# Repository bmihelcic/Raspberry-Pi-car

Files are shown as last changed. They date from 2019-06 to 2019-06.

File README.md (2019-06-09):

# Raspberry-Pi-car
Rpi car using L298n H-bridge.
You can either drive the car with your keyboard over ssh or you can download an app and drive the car over Bluetooth.

In this case battery pack was made from 3 Li-ion cells (18650 batteries) connected in series, outputing around 12V together. 12V were directly attached to Vin pin of the L298 module (with a switch in between), and also buck-converter was used to provide stable 5V (5.08 to be precise) to the Raspberry. It's worth to mention that buck converter's output should be calibrated to around 5.05 - 5.1 V otherwise Rpi reboots constantly because of inproper voltage. Also, Raspberry was running Raspbian OS.

There are also two 3D printed parts in the front for HC-sr04 sensors so it can be programmed for autonomous driving. Be sure to print one part as it is, and one which is mirrored. That could easily be done in slicer software like "Cura".
This mod is not fully developed, and obviously more sensors are needed.

Pin connections between Raspberry and L298 module

| Name | wiringPi | BCM	  | Physical |
| ---  |:---:| -----:| ---:|
| in1  | 0 | 17 	  | 11 |
| in2  | 1  	  | 18 	  | 12 | 
| in3  | 2  	  | 27 	  | 13 | 
| in4  | 3  	  | 22 | 15 |
| enA  | 26 	  | 12 | 32 | 
| enB  | 23 	  | 13 | 33 | 

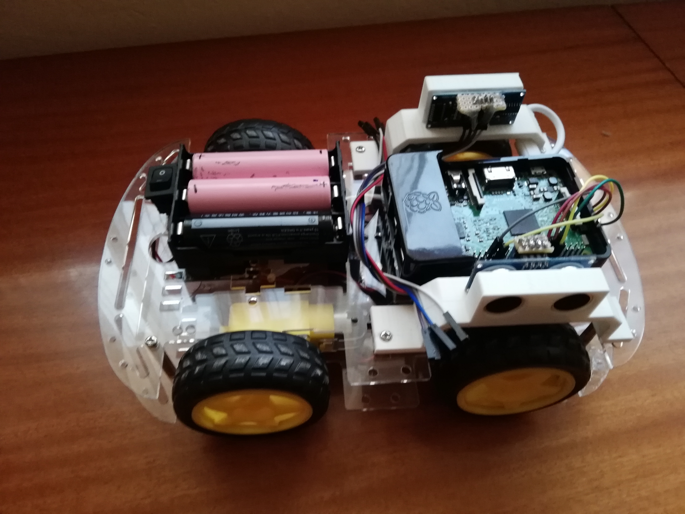
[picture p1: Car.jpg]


Parts list:<br>
<ul>
<li>1 set 4WD smart robot car chassis kit
<li>1 L298n DC motor driver module
<li>1 DC-DC buck converter
<li>1 battery holder for 3x 18650 Li-ion cells
<li>1 switch
<li>1 female USB type A connector (<i>optional</i>)
<li>1 micro USB cable
<li>x hot glue
<li>x doupont cables
<li>x soldering iron
<li>x wire cutter
</ul>

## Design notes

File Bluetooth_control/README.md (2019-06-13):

# Raspberry-Pi-car
Rpi car using L298n H-bridge and controlling with "Bluetooth RC Controller app".

Steps:
1. Firstly download "Arduino Bluetooth RC Car" app by Andi.Co on your smartphone.
2. Open file "sudo nano /etc/systemd/system/dbus-org.bluez.service" on Raspberry and edit two lines, it should look like:<br>
 	ExecStart=/usr/lib/bluetooth/bluetoothd -C<br>
	ExecStartPost=/usr/bin/sdptool add SP
3. Turn on Bluetooth on Raspberry and pair it with your phone (You need to pair mac addresses using "sudo bluetoothctl" command).
4. type "sudo rfcomm watch hci0" in terminal
5. In app on your phone, connect to Raspberry
6. Open another terminal and run script with "./bluetooth.py"
7. Drive :)

If you want raspberry to automatically (on reboot) listen for bluetooth connection and run the programm so you can drive right away, edit cron jobs using "sudo crontab -e" command and at the end of the file add: "@reboot /home/pi/Raspberry-Pi-car/Bluetooth_control/pi_blt_startup.sh".

You also have to install 2 modules:

sudo apt install rpi.gpio<br>
sudo pip3 install pyserial<br>

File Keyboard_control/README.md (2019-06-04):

# Raspberry-Pi-car
Rpi car using L298n H-bridge over ssh connection.

compile with:
gcc -Wall -lwiringPi keyboard_control.c -o keyboard_control

run with:
sudo ./keyboard_control

Control over ssh using keyboard.<br>
w - forward<br>
a - turn left<br>
d - turn right<br>
s - stop<br>
r - reverse<br>
1 - speed 1<br>
2 - speed 2<br>
3 - speed 3<br>
0 - speed 0 (stop)<br>

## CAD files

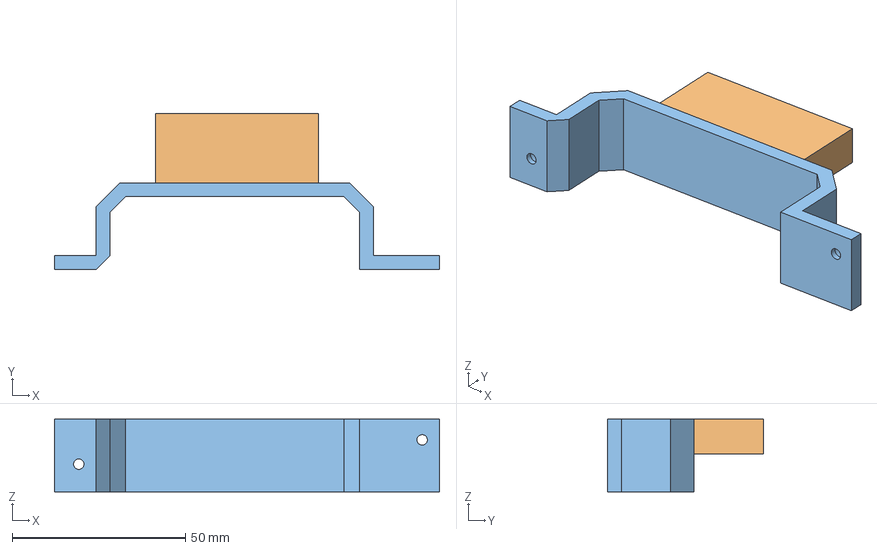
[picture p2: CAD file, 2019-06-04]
3D_part/3d_part_Ultrasonic.FCStd
111.0 x 45.0 x 21.0 mm

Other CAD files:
3D_part/3d_part_Ultrasonic.stl

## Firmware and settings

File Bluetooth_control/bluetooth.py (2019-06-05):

#!/usr/bin/python3
import serial
import RPi.GPIO as GPIO

ENABLE_PRINT=1

class Bluetooth(object):
   def __init__(self):
      self.ser=serial.Serial()
      self.ser.baudrate=115200
      self.ser.port='/dev/rfcomm0'
      print('Connecting to '+self.ser.name+'...')
      self.ser.open()
      print(self.ser.name+' is open.')
   
   def Close(self):
      self.ser.close()
           
class Car(object):
   in1 = 17
   in2 = 18
   in3 = 27
   in4 = 22
   enA = 12
   enB = 13
   lowPwm=10
   highPwm=80
   brzina=0
   def __init__(self):
      GPIO.setwarnings(False)
      GPIO.setmode(GPIO.BCM)
      GPIO.setup(self.in1, GPIO.OUT)
      GPIO.setup(self.in2, GPIO.OUT)
      GPIO.setup(self.in3, GPIO.OUT)
      GPIO.setup(self.in4, GPIO.OUT)
      GPIO.setup(self.enA,GPIO.OUT)
      GPIO.setup(self.enB,GPIO.OUT)
      self.pwmLeft=GPIO.PWM(self.enA,50)
      self.pwmRight=GPIO.PWM(self.enB,50)
      self.pwmLeft.start(0)
      self.pwmRight.start(0)
   def destroy(self):
      if ENABLE_PRINT == 1:
         print("destroy")
      GPIO.output(self.in1,GPIO.LOW)
      GPIO.output(self.in2,GPIO.LOW)
      GPIO.output(self.in3,GPIO.LOW)
      GPIO.output(self.in4,GPIO.LOW)
      GPIO.output(self.enA,GPIO.LOW)
      GPIO.output(self.enB,GPIO.LOW)
      GPIO.cleanup()
   def forward(self):
      if ENABLE_PRINT == 1:
         print("forward")
      self.pwmLeft.ChangeDutyCycle(self.brzina)
      self.pwmRight.ChangeDutyCycle(self.brzina)
      GPIO.output(self.in1,GPIO.LOW)
      GPIO.output(self.in2,GPIO.HIGH)
      GPIO.output(self.in3,GPIO.LOW)
      GPIO.output(self.in4,GPIO.HIGH)
   def reverse(self):
      if ENABLE_PRINT == 1:
         print("reverse")
      self.pwmLeft.ChangeDutyCycle(self.brzina)
      self.pwmRight.ChangeDutyCycle(self.brzina)
      GPIO.output(self.in1,GPIO.HIGH)
      GPIO.output(self.in2,GPIO.LOW)
      GPIO.output(self.in3,GPIO.HIGH)
      GPIO.output(self.in4,GPIO.LOW)
   def turn_left(self):
      if ENABLE_PRINT == 1:
         print("turn_left")
      self.pwmLeft.ChangeDutyCycle(self.brzina)
      self.pwmRight.ChangeDutyCycle(0)
      GPIO.output(self.in1,GPIO.LOW)
      GPIO.output(self.in2,GPIO.HIGH)
      GPIO.output(self.in3,GPIO.LOW)
      GPIO.output(self.in4,GPIO.LOW)
   def turn_right(self):
      if ENABLE_PRINT == 1:
         print("turn_right")
      self.pwmLeft.ChangeDutyCycle(0)
      self.pwmRight.ChangeDutyCycle(self.brzina)
      GPIO.output(self.in1,GPIO.LOW)
      GPIO.output(self.in2,GPIO.LOW)
      GPIO.output(self.in3,GPIO.LOW)
      GPIO.output(self.in4,GPIO.HIGH)
   def stop(self):
      if ENABLE_PRINT == 1:
         print("stop")
      GPIO.output(self.in1,GPIO.LOW)
      GPIO.output(self.in2,GPIO.LOW)
      GPIO.output(self.in3,GPIO.LOW)
      GPIO.output(self.in4,GPIO.LOW)
   def forward_left(self):
      if ENABLE_PRINT == 1:
         print("forward_left")
      GPIO.output(self.in1,GPIO.LOW)
      GPIO.output(self.in2,GPIO.HIGH)
      GPIO.output(self.in3,GPIO.LOW)
      GPIO.output(self.in4,GPIO.HIGH)
      self.pwmLeft.ChangeDutyCycle(self.highPwm)
      self.pwmRight.ChangeDutyCycle(self.lowPwm)
   def forward_right(self):
      if ENABLE_PRINT == 1:
         print("forward_right")
      GPIO.output(self.in1,GPIO.LOW)
      GPIO.output(self.in2,GPIO.HIGH)
      GPIO.output(self.in3,GPIO.LOW)
      GPIO.output(self.in4,GPIO.HIGH)
      self.pwmLeft.ChangeDutyCycle(self.lowPwm)
      self.pwmRight.ChangeDutyCycle(self.highPwm)
   def backward_left(self):
      if ENABLE_PRINT == 1:
         print("backward_left")
      GPIO.output(self.in1,GPIO.HIGH)
      GPIO.output(self.in2,GPIO.LOW)
      GPIO.output(self.in3,GPIO.HIGH)
      GPIO.output(self.in4,GPIO.LOW)
      self.pwmLeft.ChangeDutyCycle(self.highPwm)
      self.pwmRight.ChangeDutyCycle(self.lowPwm)
   def backward_right(self):
      if ENABLE_PRINT == 1:
         print("backward_right")
      GPIO.output(self.in1,GPIO.HIGH)
      GPIO.output(self.in2,GPIO.LOW)
      GPIO.output(self.in3,GPIO.HIGH)
      GPIO.output(self.in4,GPIO.LOW)
      self.pwmLeft.ChangeDutyCycle(self.lowPwm)
      self.pwmRight.ChangeDutyCycle(self.highPwm)
   def speed_zero(self):
      if ENABLE_PRINT == 1:
         print("speed_zero")
      self.brzina=0
   def speed_one(self):
      if ENABLE_PRINT == 1:
         print("speed_one")
      self.brzina=10
   def speed_two(self):
      if ENABLE_PRINT == 1:
         print("speed_two")
      self.brzina=20
   def speed_three(self):
      if ENABLE_PRINT == 1:
         print("speed_three")
      self.brzina=30
   def speed_four(self):
      if ENABLE_PRINT == 1:
         print("speed_four")
      self.brzina=40
   def speed_five(self):
      if ENABLE_PRINT == 1:
         print("speed_five")
      self.brzina=50
   def speed_six(self):
      if ENABLE_PRINT == 1:
         print("speed_six")
      self.brzina=60
   def speed_seven(self):
      if ENABLE_PRINT == 1:
         print("speed_seven")
      self.brzina=70
   def speed_eight(self):
      if ENABLE_PRINT == 1:
         print("speed_eight")
      self.brzina=80
   def speed_nine(self):
      if ENABLE_PRINT == 1:
         print("speed_nine")
      self.brzina=90
   def speed_ten(self):
      if ENABLE_PRINT == 1:
         print("speed_ten")
      self.brzina=100
       
def loop():
   while True:
      rx=Bluetooth.ser.read(1)
      options[rx](Raspberry_car)

options={
    b'F':Car.forward,
    b'B':Car.reverse,
    b'L':Car.turn_left,
    b'R':Car.turn_right,
    b'G':Car.forward_left,
    b'I':Car.forward_right,
    b'H':Car.backward_left,
    b'J':Car.backward_right,
    b'S':Car.stop,
    b'0':Car.speed_zero,
    b'1':Car.speed_one,
    b'2':Car.speed_two,
    b'3':Car.speed_three,
    b'4':Car.speed_four,
    b'5':Car.speed_five,
    b'6':Car.speed_six,
    b'7':Car.speed_seven,
    b'8':Car.speed_eight,
    b'9':Car.speed_nine,
    b'q':Car.speed_ten
}

if __name__ == '__main__':
   Raspberry_car=Car()
   Bluetooth=Bluetooth()

   try:
      loop()
   except KeyboardInterrupt:
      Car.destroy(Raspberry_car)
      Bluetooth.Close()

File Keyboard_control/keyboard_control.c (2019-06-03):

#include <stdio.h>
#include <termios.h>
#include <unistd.h>
#include <fcntl.h>
#include <wiringPi.h>
 
int kbhit(void);
#define in1 0
#define in2 1
#define in3 2
#define in4 3
#define enA 26
#define enB 23


void forward();
void turn_right();
void turn_left();
void stop();
void reverse();

 
int main(void)
{
  wiringPiSetup();
  char last_key='s';
  char new_key='s';
  pinMode(in1,OUTPUT);
  pinMode(in2,OUTPUT);
  pinMode(in3,OUTPUT);
  pinMode(in4,OUTPUT);
  pinMode(enA,PWM_OUTPUT);
  pinMode(enB,PWM_OUTPUT);
  
  while(1){
    while(!kbhit()){
        if(new_key!=last_key){
            last_key=new_key;
            switch(new_key){
                case 'w':
                    forward();
                    printf("forward\n");
                    break;
                case 'a':
                    turn_left();
                    printf("left\n");
                    break;
                case 's':
                    stop();
                    printf("stop\n");
                    break;
                case 'd':
                    turn_right();
                    printf("right\n");
                    break;
                case 'r':
                    reverse();
                    printf("reverse\n");
                    break;
                case '1':
                    pwmWrite(enA,310);
                    pwmWrite(enB,310);
                    printf("Brzina 1\n");
                    break;
                case '2':
                    pwmWrite(enA,400);
                    pwmWrite(enB,400);
                    printf("Brzina 2\n");
                    break;
                case '3':
                    pwmWrite(enA,600);
                    pwmWrite(enB,600);
                    printf("Brzina 3\n");
                    break;
                case '0':
                    pwmWrite(enA,0);
                    pwmWrite(enB,0);
                    printf("Brzina 0\n");
                    break;
            }
        }
    }
    new_key=getchar();
  }
  return 0;
}

int kbhit(void)
{
  struct termios oldt, newt;
  int ch;
  int oldf;
 
  tcgetattr(STDIN_FILENO, &oldt);
  newt = oldt;
  newt.c_lflag &= ~(ICANON | ECHO);
  tcsetattr(STDIN_FILENO, TCSANOW, &newt);
  oldf = fcntl(STDIN_FILENO, F_GETFL, 0);
  fcntl(STDIN_FILENO, F_SETFL, oldf | O_NONBLOCK);
 
  ch = getchar();
 
  tcsetattr(STDIN_FILENO, TCSANOW, &oldt);
  fcntl(STDIN_FILENO, F_SETFL, oldf);
 
  if(ch != EOF)
  {
    ungetc(ch, stdin);
    return 1;
  }
 
  return 0;
}

void forward(){
    digitalWrite(in1,LOW);
    digitalWrite(in2,HIGH);
    digitalWrite(in3,LOW);
    digitalWrite(in4,HIGH);
}
void turn_right(){
    digitalWrite(in1,LOW);
    digitalWrite(in2,LOW);
    digitalWrite(in3,LOW);
    digitalWrite(in4,HIGH);
}
void turn_left(){
    digitalWrite(in1,LOW);
    digitalWrite(in2,HIGH);
    digitalWrite(in3,LOW);
    digitalWrite(in4,LOW);
}
void stop(){
    digitalWrite(in1,LOW);
    digitalWrite(in2,LOW);
    digitalWrite(in3,LOW);
    digitalWrite(in4,LOW);
}
void reverse(){
    digitalWrite(in1,HIGH);
    digitalWrite(in2,LOW);
    digitalWrite(in3,HIGH);
    digitalWrite(in4,LOW);
}

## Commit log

2019-06-03 table with pin connections
2019-06-04 added 3d printing parts
    [3d_part_Ultrasonic.FCStd, 3d_part_Ultrasonic.stl]
